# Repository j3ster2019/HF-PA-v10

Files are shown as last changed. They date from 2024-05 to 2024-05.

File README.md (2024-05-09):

Why?

We need a QRP PA which does NOT blow up (unlike those 3xBS170 and 4xBS170
designs). We believe that if the FETs blow up (despite best practices and
intentions but under less-than-ideal external conditions), then the design has
FAILED!

[Inspirational Video Link](https://www.youtube.com/watch?v=4r7wHMg5Yjg)

Important update (February-2024): LC match for IRF510 @ 28 MHz. 7 turns FT50-6
and 220pF capacitor. Corrected PAE figure is around 50%. 30v @ drain produces
roughly 10W of clean'ish looking RF output. 24v @ drain produces 6W @ 28 MHz.
17v @ drain produces 3.7W.

March-2024 update: LC match for IRF510 @ 50 MHz. T50-6 4 turns and 180pF
capacitor. 24v @ drain produces clean'ish 28.8 Vpp (~2W). PAE is around 25%.
Such is life...

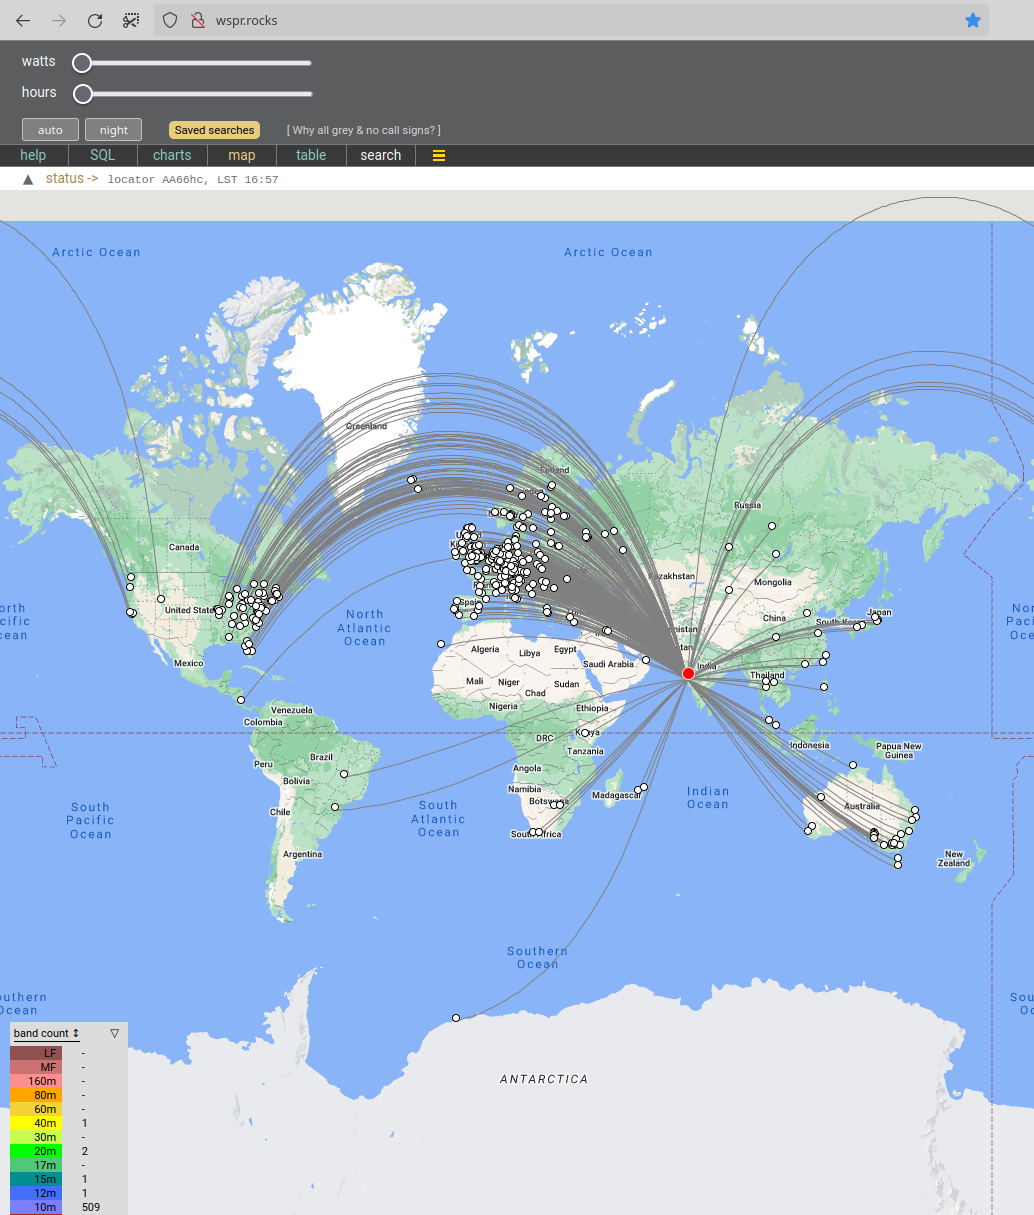
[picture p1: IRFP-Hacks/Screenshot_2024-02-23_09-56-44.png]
WSPR results


Update (29-September-2023): By removing the gate resistor, we firmly push the
amplifier into more Class-D operation. The MOSFET now remains as cool as a
cucumber!

Update (10-September-2023): The PCB was successfully validated!

Output is 7 to 8 W (before LPF) over a range of 160m to 10m as expected, with a
15V SMPS power supply. With a Pro-BPF attached, the power output is ~5W even at
28 MHz with IRF510! It even puts out 2W @ 50 MHz!

Amplifier characterization (@ 30.7 MHz for some reason, before LPF):

7 volts -> 2W

8 volts -> 3W

9 volts -> 3.5W

10 volts -> 4W

11 volts -> 5W

12 volts -> 6W

14 volts -> 8W

Efficiency is in the range of 45 to 50% which isn't bad ;)

Another result: 17 volts. 14 MHz. NKK LPF. 17.3W DC in. 57.6 clean Vpp on
scope. 8.3W clean RF output @ 48% efficiency!

BOM cost (minimal version): < 450 INR only - beat this! ;)

Note: HF-PA-v10 is also known as `CoolAMP (TM)`.

Build Notes:

- Use a 15V / 16v power supply.

- If you want to use a 13.8V power supply, then

  - Do NOT install the 78M12 regulator

  - Bridge the JP2 jumper

- Use adequate heatsinking. I use a 100x100x200 aluminium block with a 12v fan
  for doing WSPR activities. The MOSFET temperature stays under 45 degrees this
  way.

- PTT is active high - 3.3v is enough to trigger PTT.

- To skip the PTT sub-circuit, bridge the AOD407 MOSFET's source to drain.

- This amplifier can be directly driven by Si5351 (use 8mA drive setting)!

- IMPORTANT: For safety and RF output control, use a `10A DC-DC Step-down
  Adjustable Constant Voltage Module` or something similar.

  - https://robu.in/product/10a-dc-dc-step-down-adjustable-constant-voltage-module/

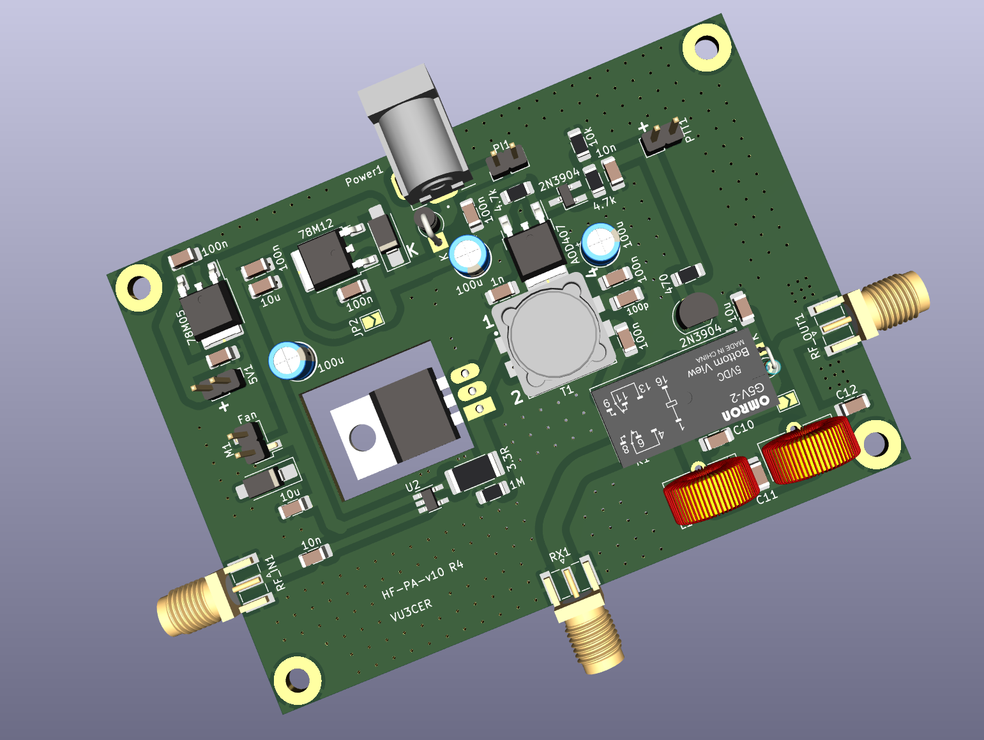
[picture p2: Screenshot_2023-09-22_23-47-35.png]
PA 1


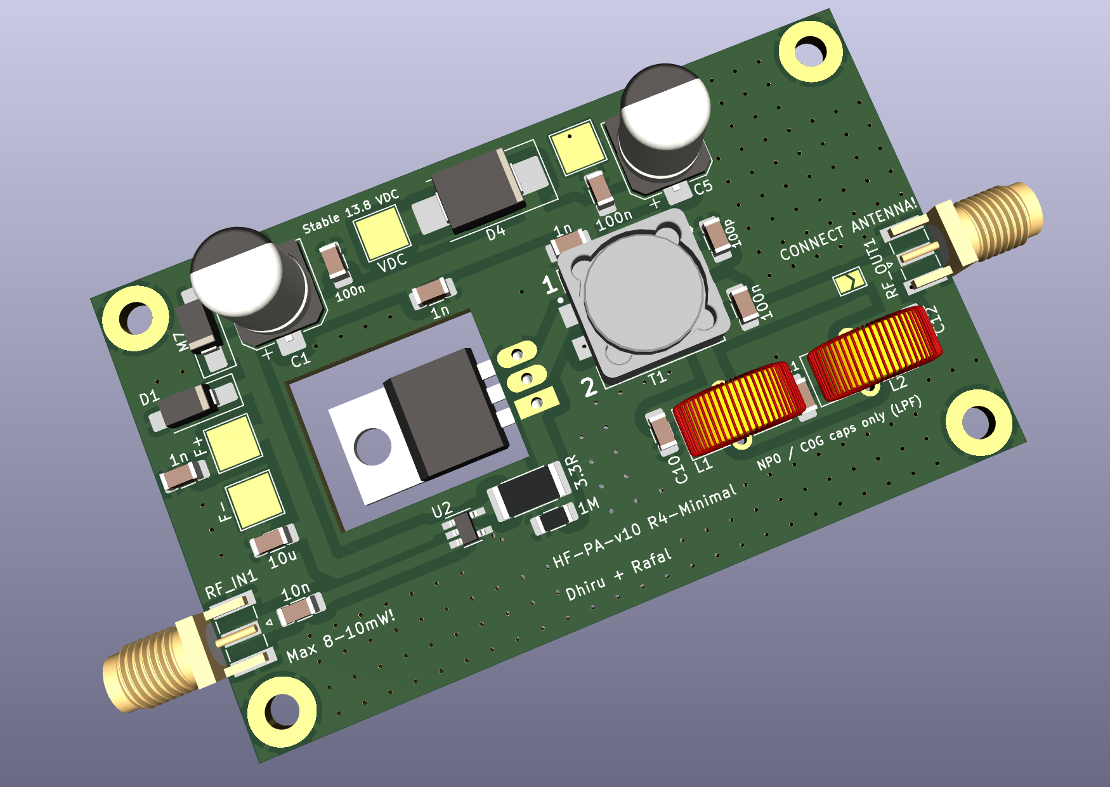
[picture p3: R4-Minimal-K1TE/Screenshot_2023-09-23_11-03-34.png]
PA Minimal


Results:

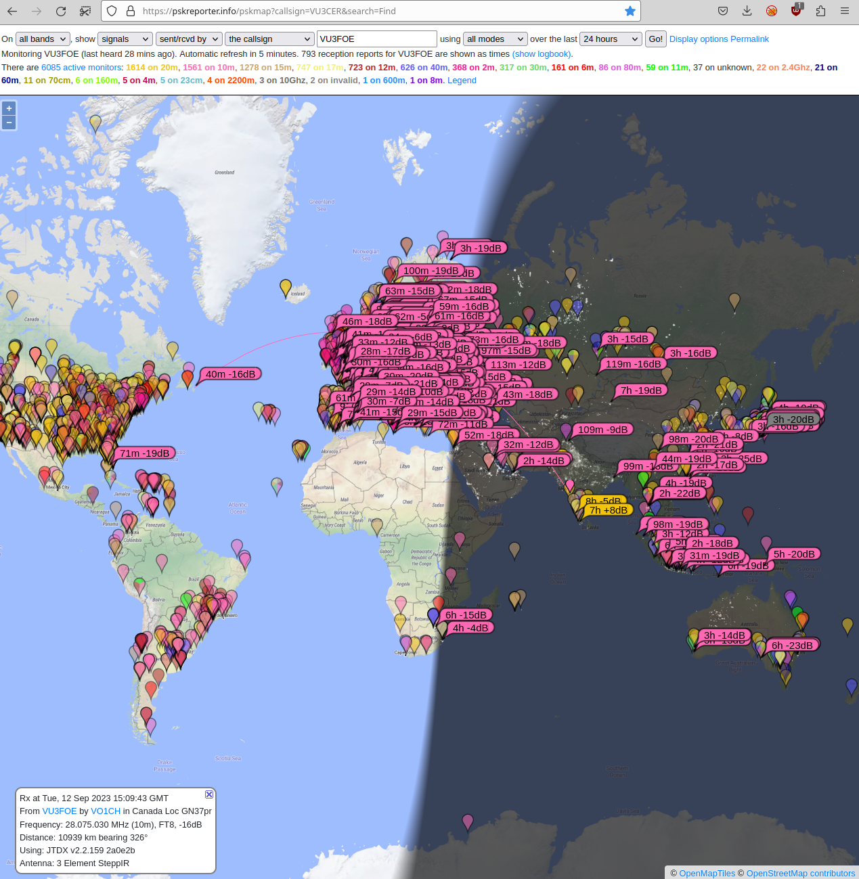
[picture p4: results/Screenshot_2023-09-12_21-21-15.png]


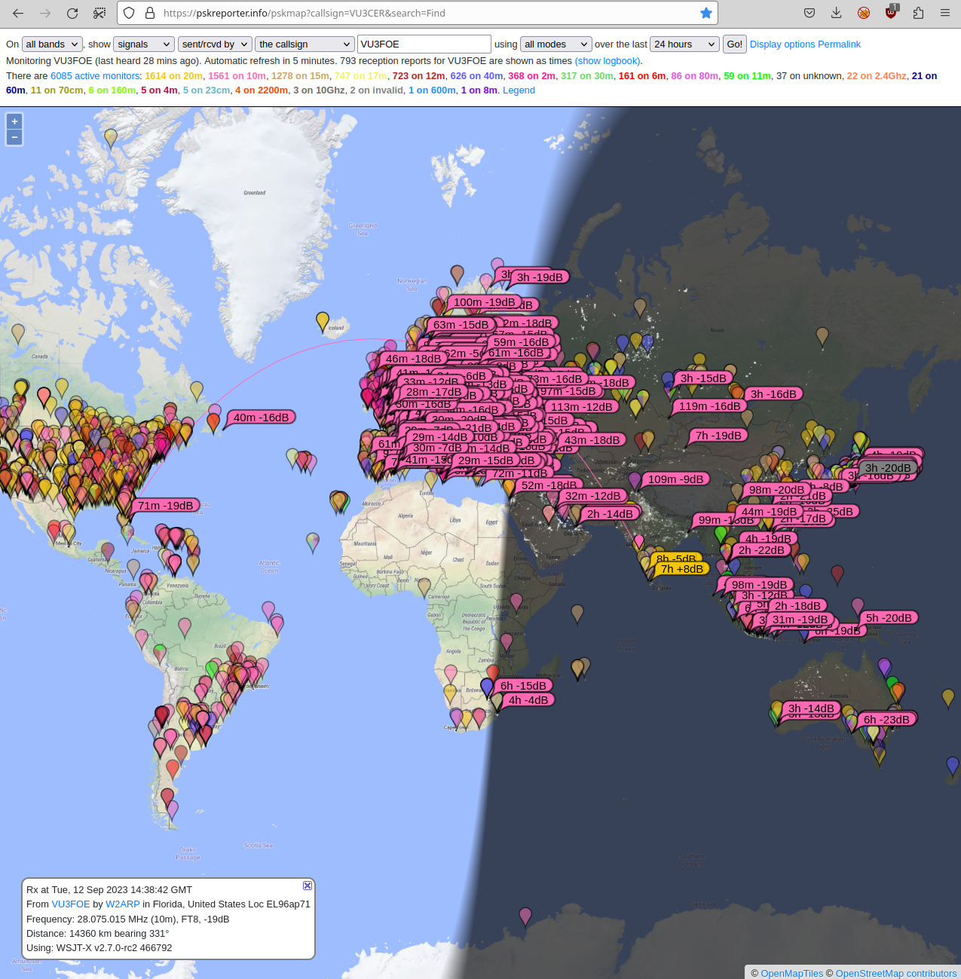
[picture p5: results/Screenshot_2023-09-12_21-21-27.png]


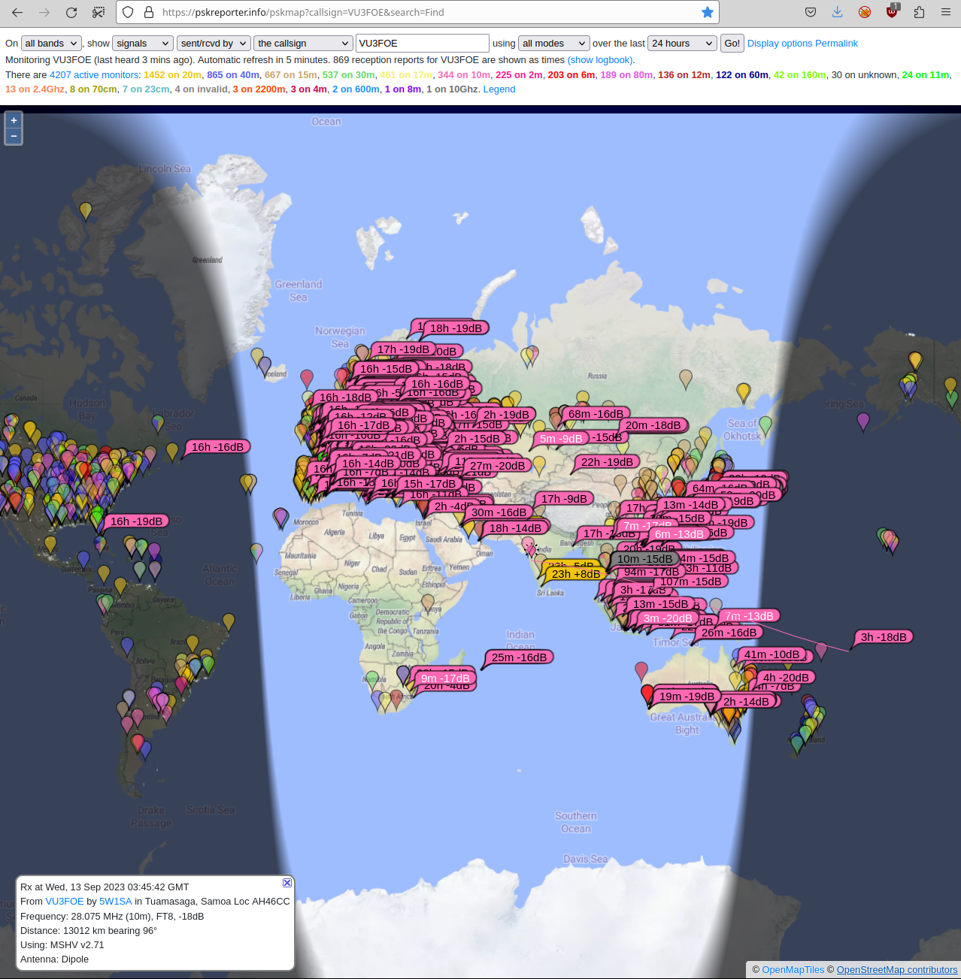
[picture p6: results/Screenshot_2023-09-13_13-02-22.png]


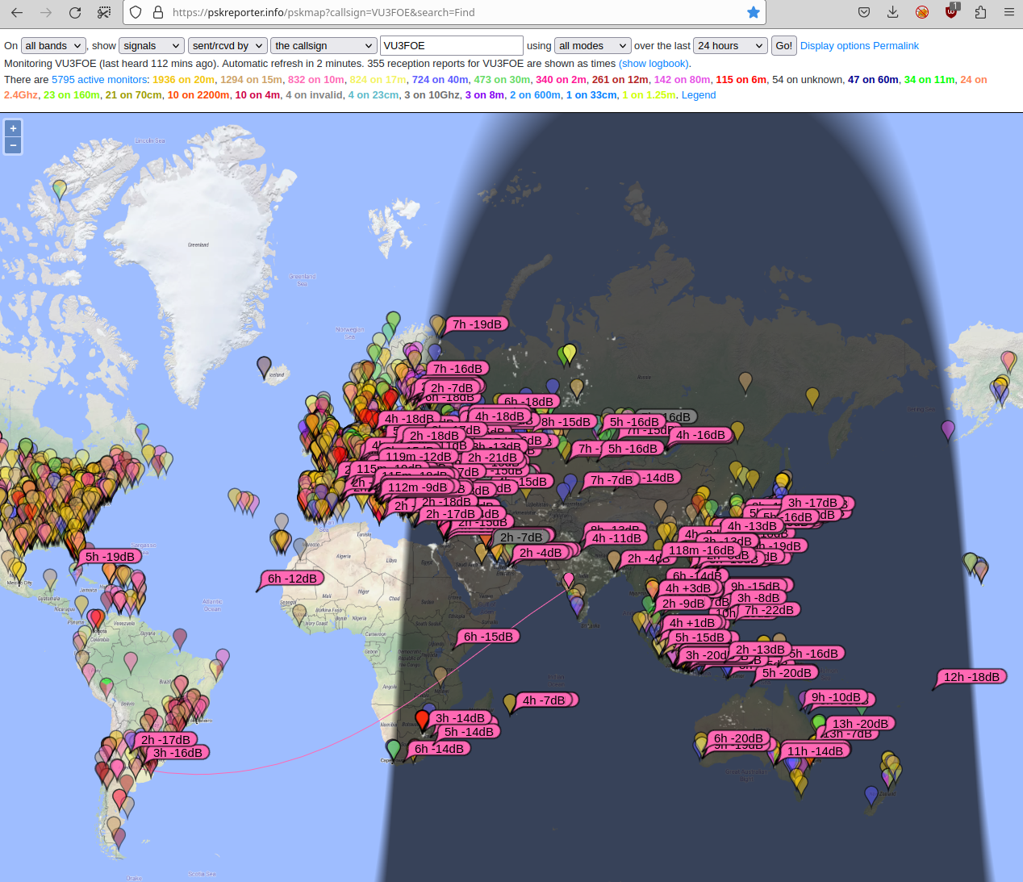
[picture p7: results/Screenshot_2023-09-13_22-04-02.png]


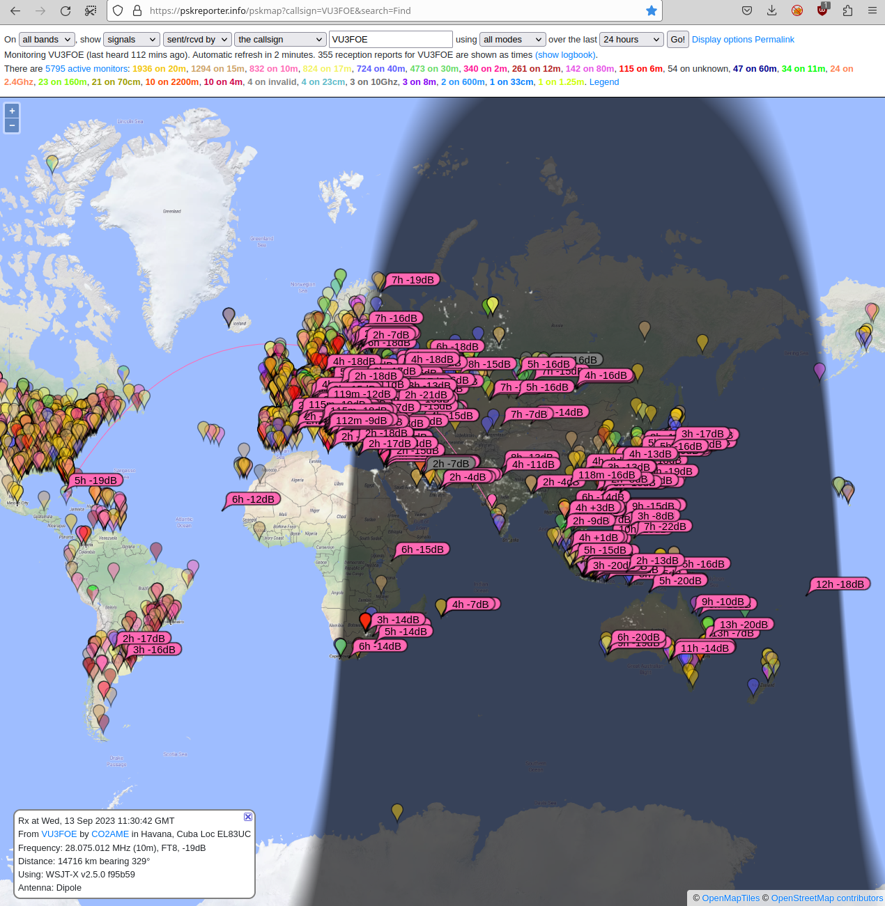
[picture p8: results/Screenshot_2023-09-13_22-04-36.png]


Fun on WSPR:

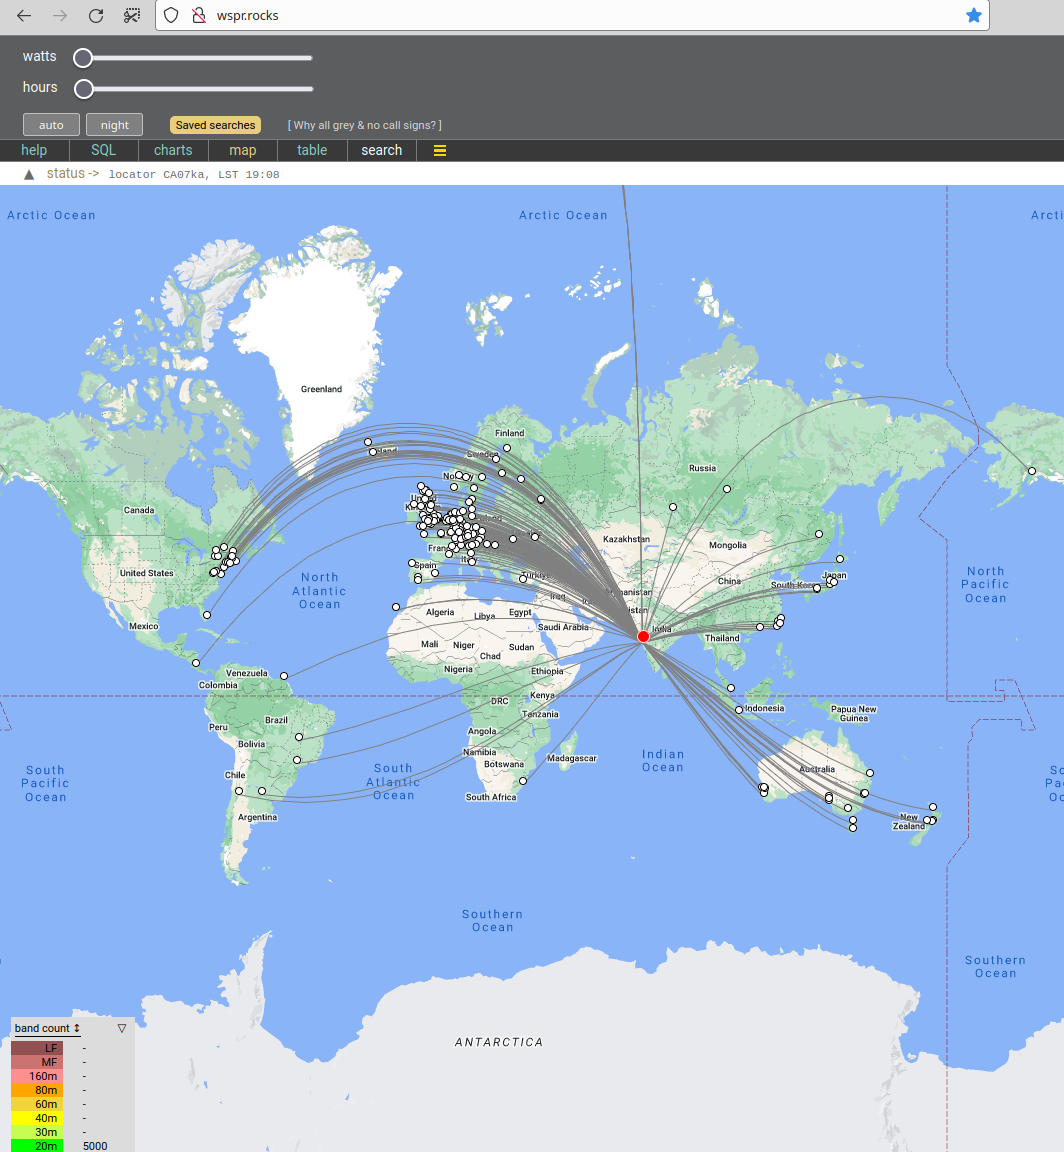
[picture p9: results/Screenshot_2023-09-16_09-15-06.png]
WSPR 1


Note: I am using a 5-meter long EFHW antenna tuned for the 10m band along with
~45 meters of HLF-240 coax. Your results should be better than mine ;)

Quick Hacks:

I am using one v10 board (on low power setting of ~1 to 2W) to drive the second
v10 board.

The second v10 board has IRF530 on it. It uses a simple 3R3 SMD drain choke,
240nH inductor (8 turns on T50-6) + 470 pF LC match for the 20m band at the
output side.

The power output is 20W+ with 30v at the IRF530 drain. While this is fine for
FT8, we decrease the output power to 9 to 12W for WSPR mode (considering
derating, heat dissipation, fear of "flash over")

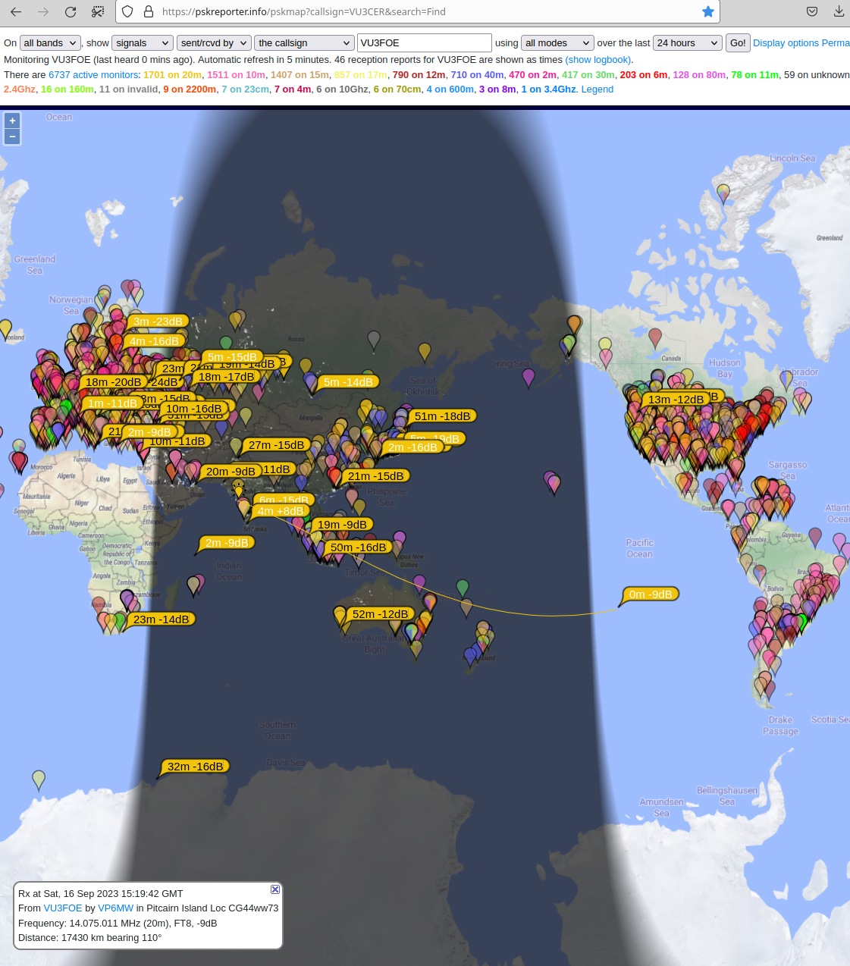
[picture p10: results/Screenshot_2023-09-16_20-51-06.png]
Results for IRF530 hack


December-2023 update: We can now use IRFP140N (with its massive TO-247 package)
to generate around "20W" safely for WSPR. We drive the IRFP140N MOSFET directly
with the UCC driver chip now.

Settings: UCC driver at roughly 12v. With LC match set for 20m band (NB!).

IRFP140N @ 28v drain @ 14 MHz -> 22W

IRFP140N @ 28v drain @ 3.5 MHz -> 20W (for Rafal)

IRFP140N @ 28v drain @ 7 MHz -> 20W

We believe we can push 25W easily by feeding 14v to 15v to the UCC driver chip.

The "final" IRFP140N MOSFET remains as cool as a cucumber, pretty boring -
right? Where have the "exciting" days of the MOSFETs blowing up in your face
gone? Just kidding!

NB: To overcome antenna losses (~2.0 SWR 20m dipole), lossy 50m meters of
HLF-200 coax, we need to generate around 15W+ on the amplifier side.

```
In [1]: 15W * 0.88 (SWR losses) * 0.40 (coax losses)
Out[1]: 5.28
```

PA protection:

- We plan to use INA219 to monitor current consumption, and to terminate TX if
  anomalies are detected.

- Use `thermocouple` attached to the MOSFET's body using thermoglue to monitor
  the temperature, and to terminate TX if anomalies are detected.

New discoveries (via https://github.com/rafal-rozestwinski):

- Power output is 1 to 1.5W on 50 MHz.

  We can probably get 2 to 3W with some more work here (push the amp into more
  Class-D).

- The PA survives open and short conditions but protections are recommended in
  any case.

  - INA219 based current monitoring

  - Thermocouple based temperature monitoring

- We do NOT recommend the old-skool SWR monitoring approach due to its
  complexity (for end-users).

Learnings:

- Keep the IRF510's gate voltage <=14 volts.

  If the IRF510's gate voltage is too high (i.e. when IRF510 is over-driven),
  it results in super wide-band distorted noisy signal on the output - you
  don't want that ;)

  If you want to feed high voltages to IRF's drain, then use a regulator (12v)
  for powering the UCC driver chip.

Joining In:

Are you interested in such projects, and spam-free technical discussions?

If yes, you might be interested in joining [the 'HAMBREWERS' Telegram group](https://t.me/+TwzGyKGe8_QI_B3y).

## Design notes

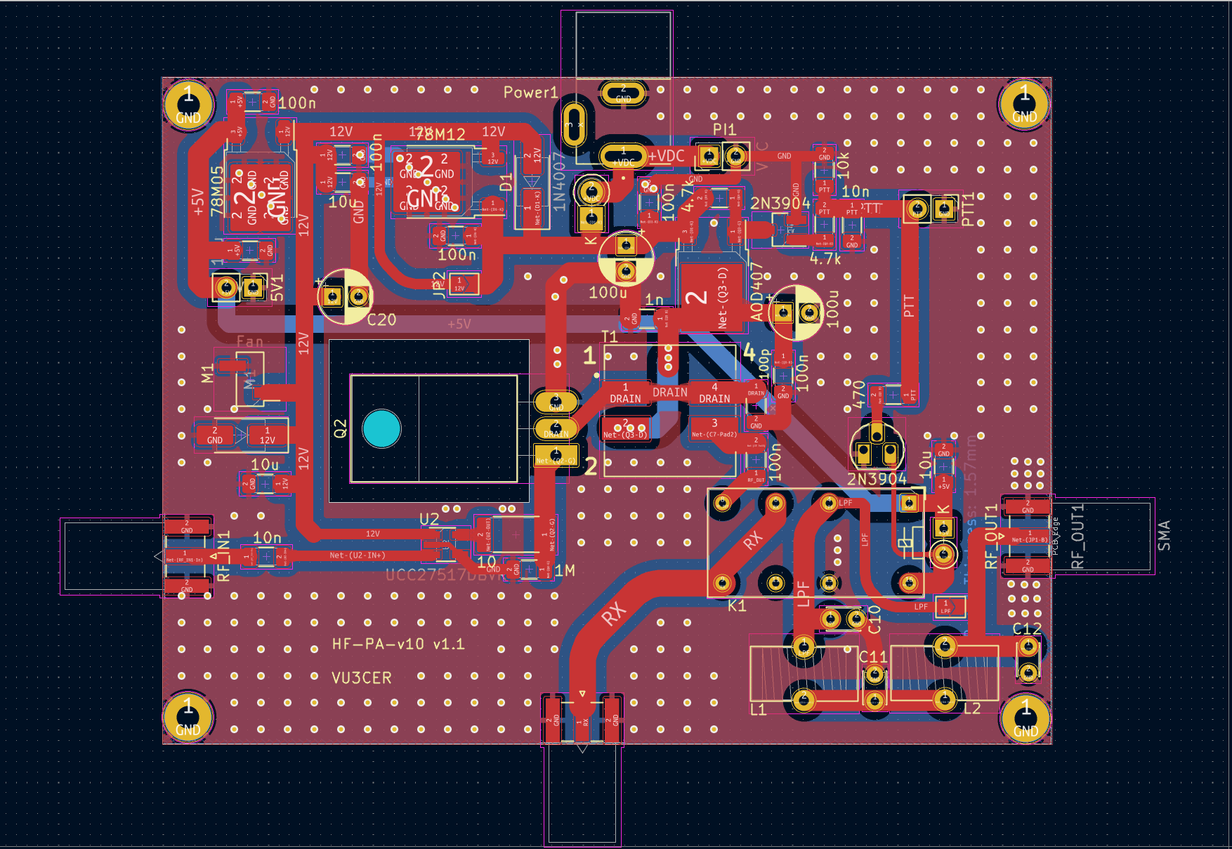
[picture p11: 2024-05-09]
Screenshot_2023-08-26_22-36-42.png

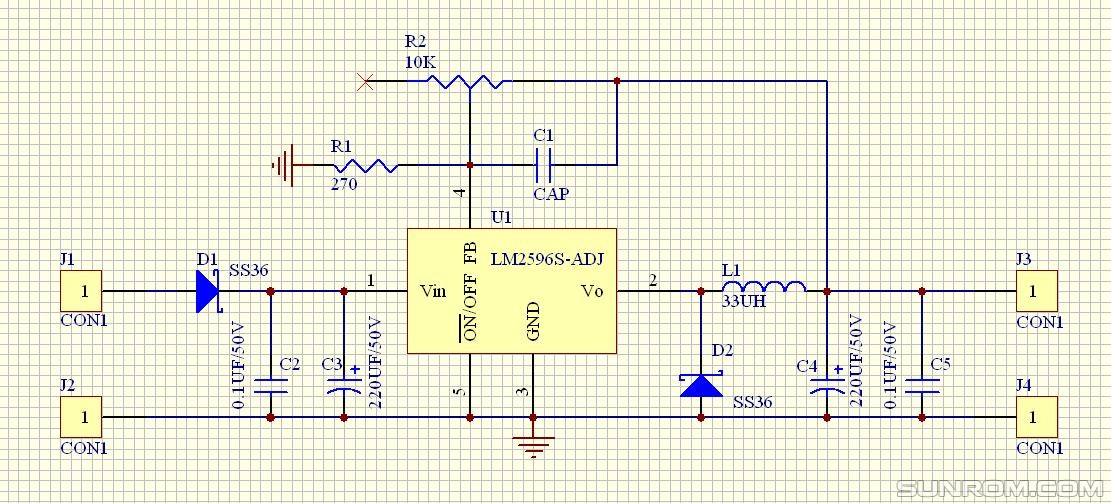
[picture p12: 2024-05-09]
FuturePowerControl/sch.jpg

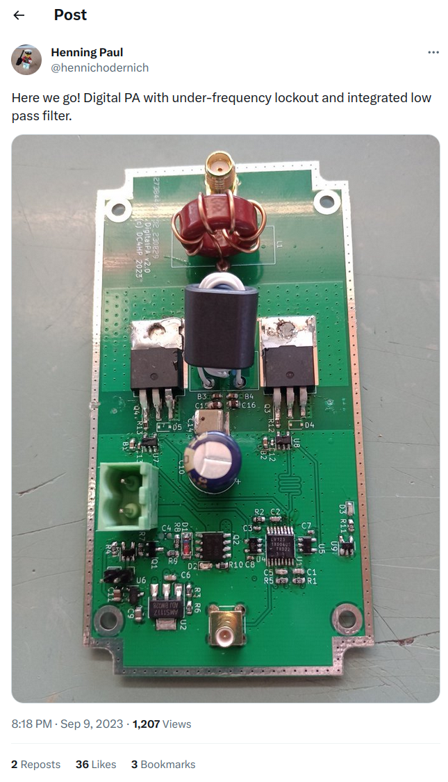
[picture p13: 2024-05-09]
info/Screenshot_2023-09-10_00-21-56.png

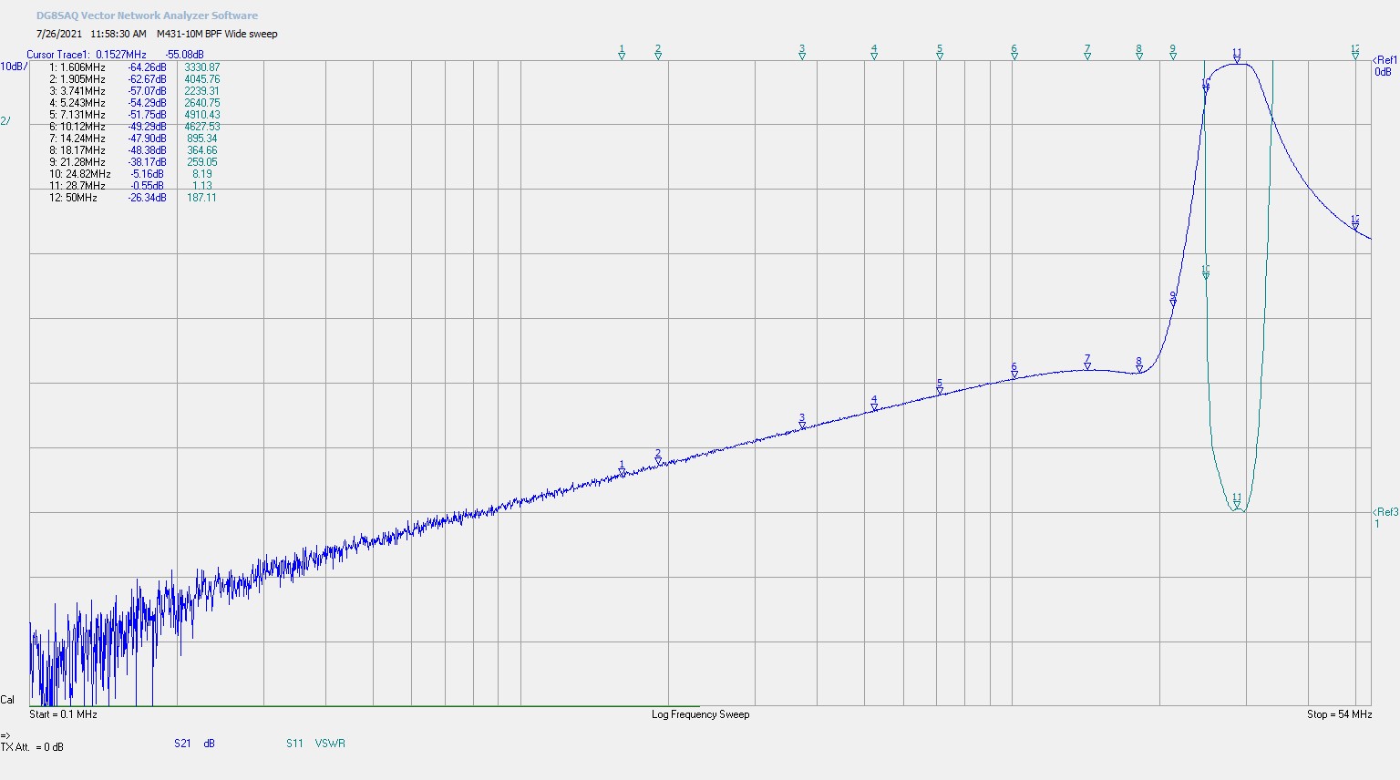
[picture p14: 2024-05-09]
info/M431_10M_Wide.jpg

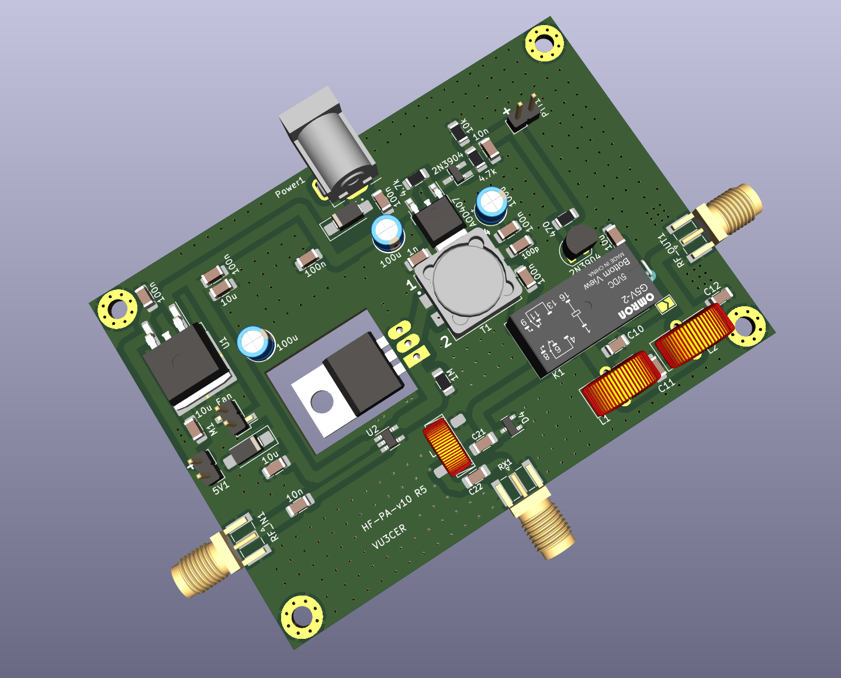
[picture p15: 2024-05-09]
R5/Screenshot_2023-10-03_14-03-06.png

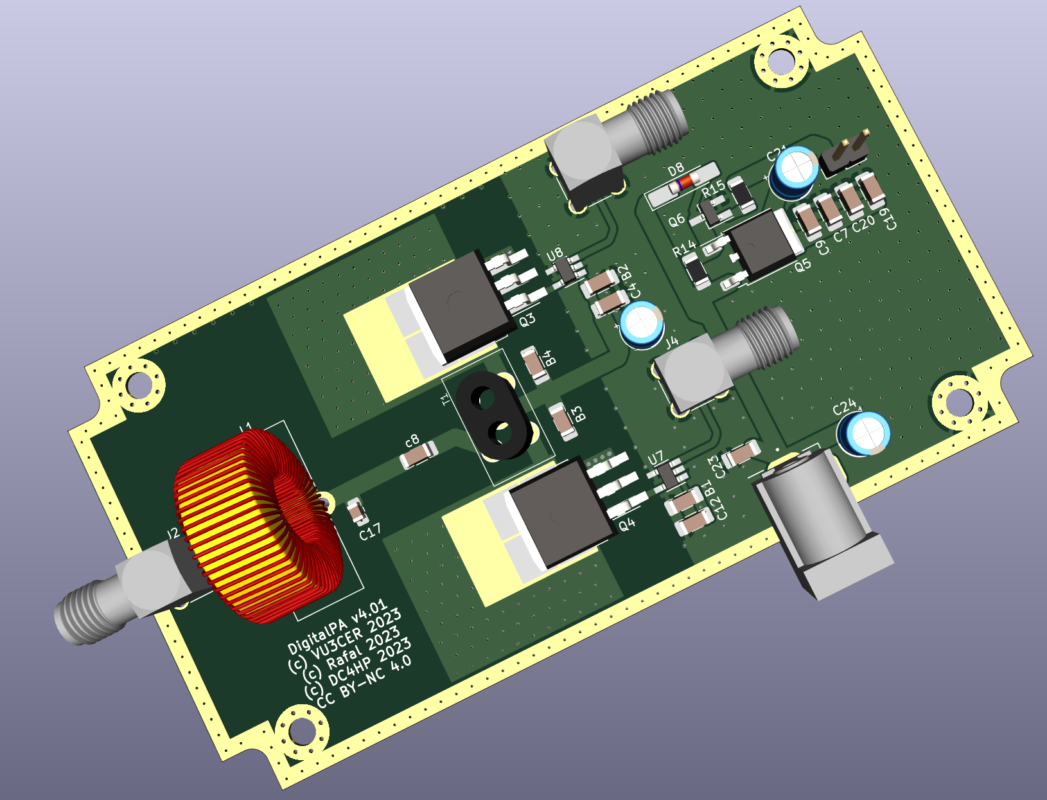
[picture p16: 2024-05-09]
Digital-PA-v3/Screenshot_2023-10-04_21-27-38.png

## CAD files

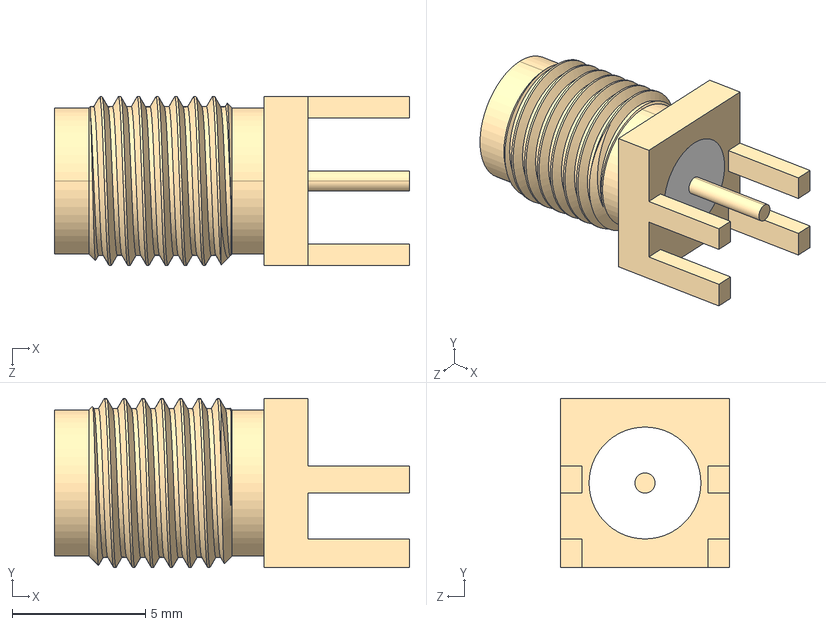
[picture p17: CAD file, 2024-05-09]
Digital-PA-v3/models/CON-SMA-EDGE-S--3DModel-STEP-56544.STEP
13.3 x 6.35 x 6.35 mm

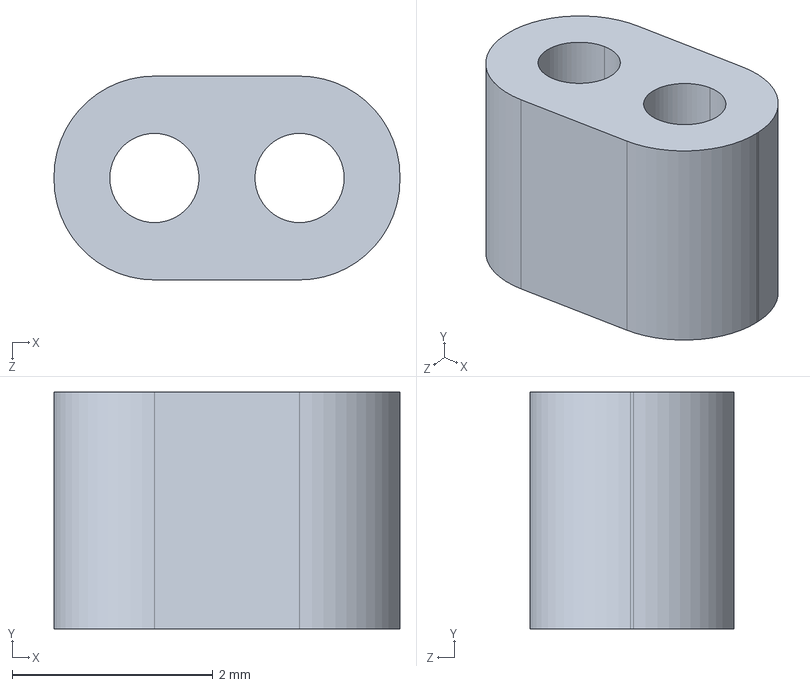
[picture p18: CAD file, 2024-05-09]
Digital-PA-v5-Prod/models/User Library-BN43-2302.STEP
3.45 x 2.36 x 2.03 mm

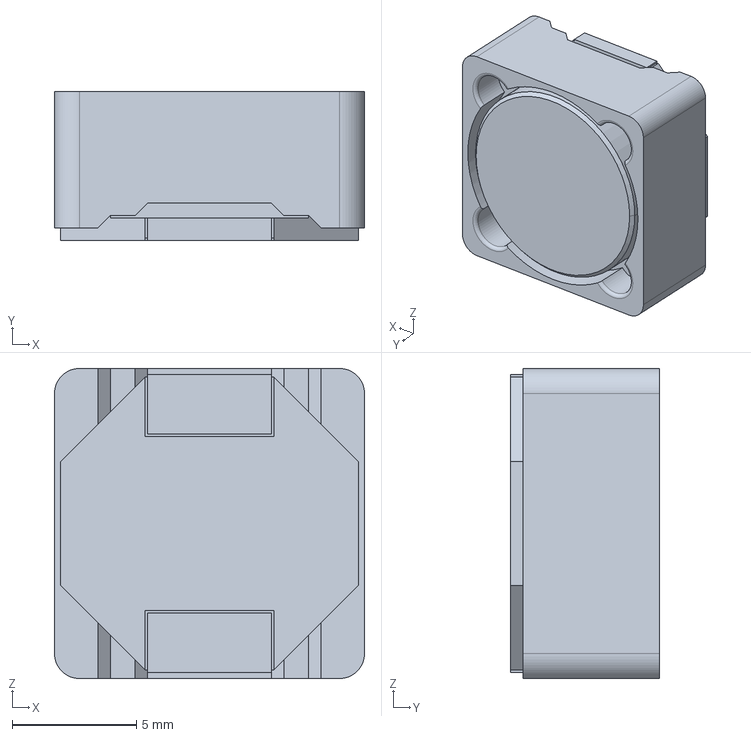
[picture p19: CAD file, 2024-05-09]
FuturePowerControl/models/SRR1260-4R7Y.stp
12.5 x 6.00 x 12.5 mm

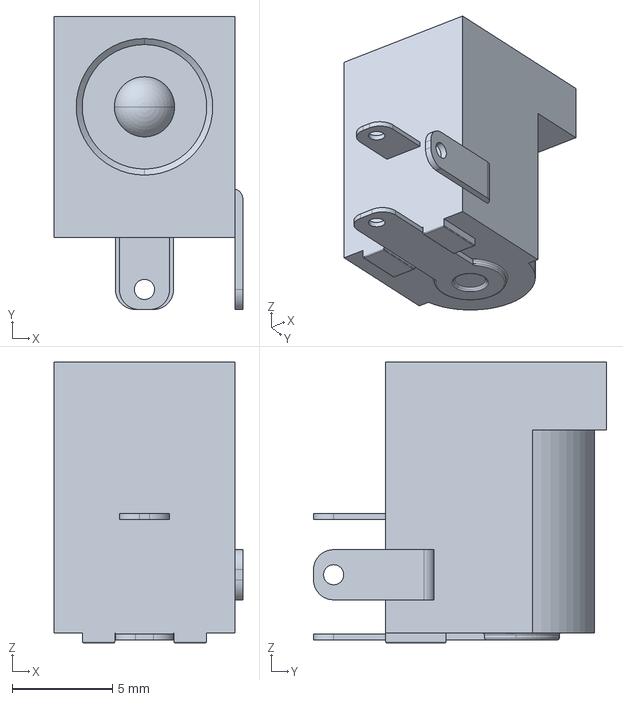
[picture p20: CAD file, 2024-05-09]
IRFP-Hacks-v4/models/DC-005-5A-2.0.step
9.40 x 14.6 x 14.0 mm

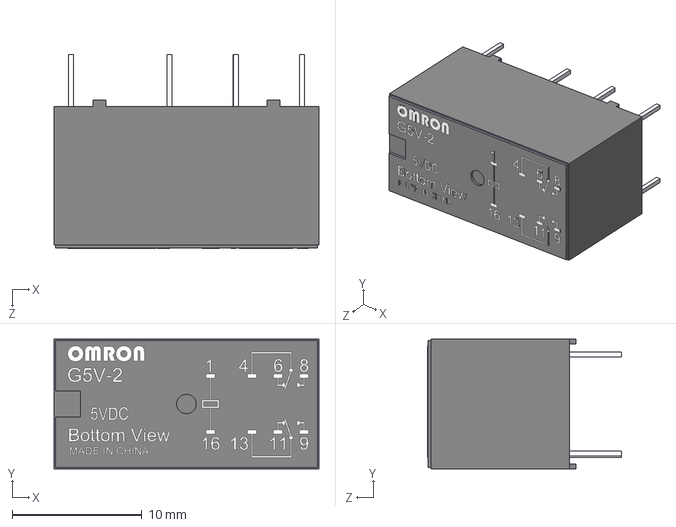
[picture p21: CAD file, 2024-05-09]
R4-Minimal-K1TE/models/User Library-OMRON G5V-2.STEP
20.4 x 10.0 x 14.9 mm

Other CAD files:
Digital-PA-v3/models/144743.stp
Digital-PA-v3/models/UCC27517DBVR.step
Digital-PA-v5-Prod/models/144743.stp
Digital-PA-v5-Prod/models/UCC27517DBVR.step
FuturePowerControl/models/UCC27517DBVR.step
IRF530-Hack/models/Inductor_7x7x2.5.STEP
IRF530-Hack/models/UCC27517DBVR.step
IRFP-Hacks-v2/models/Inductor_7x7x2.5.STEP
IRFP-Hacks-v2/models/UCC27517DBVR.step
IRFP-Hacks-v3/models/Inductor_7x7x2.5.STEP
IRFP-Hacks-v3/models/UCC27517DBVR.step
IRFP-Hacks-v4/models/Inductor_7x7x2.5.STEP
IRFP-Hacks-v4/models/TO-220-3 Bend Mirror.stp
IRFP-Hacks-v4/models/UCC27517DBVR.step
IRFP-Hacks/models/Inductor_7x7x2.5.STEP
IRFP-Hacks/models/UCC27517DBVR.step
MRF101-Hack/models/DG340-3.81-02P-12-00AH.STEP
MRF101-Hack/models/Inductor_7x7x2.5.STEP
MRF101-Hack/models/Screw-Terminal-P5.08.step
MRF101-Hack/models/UCC27517DBVR.step
MRF101-Hack/models/User Library-3386P.STEP
MRF101-Hack/models/WE-CAIR_4248 (rev1).stp
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

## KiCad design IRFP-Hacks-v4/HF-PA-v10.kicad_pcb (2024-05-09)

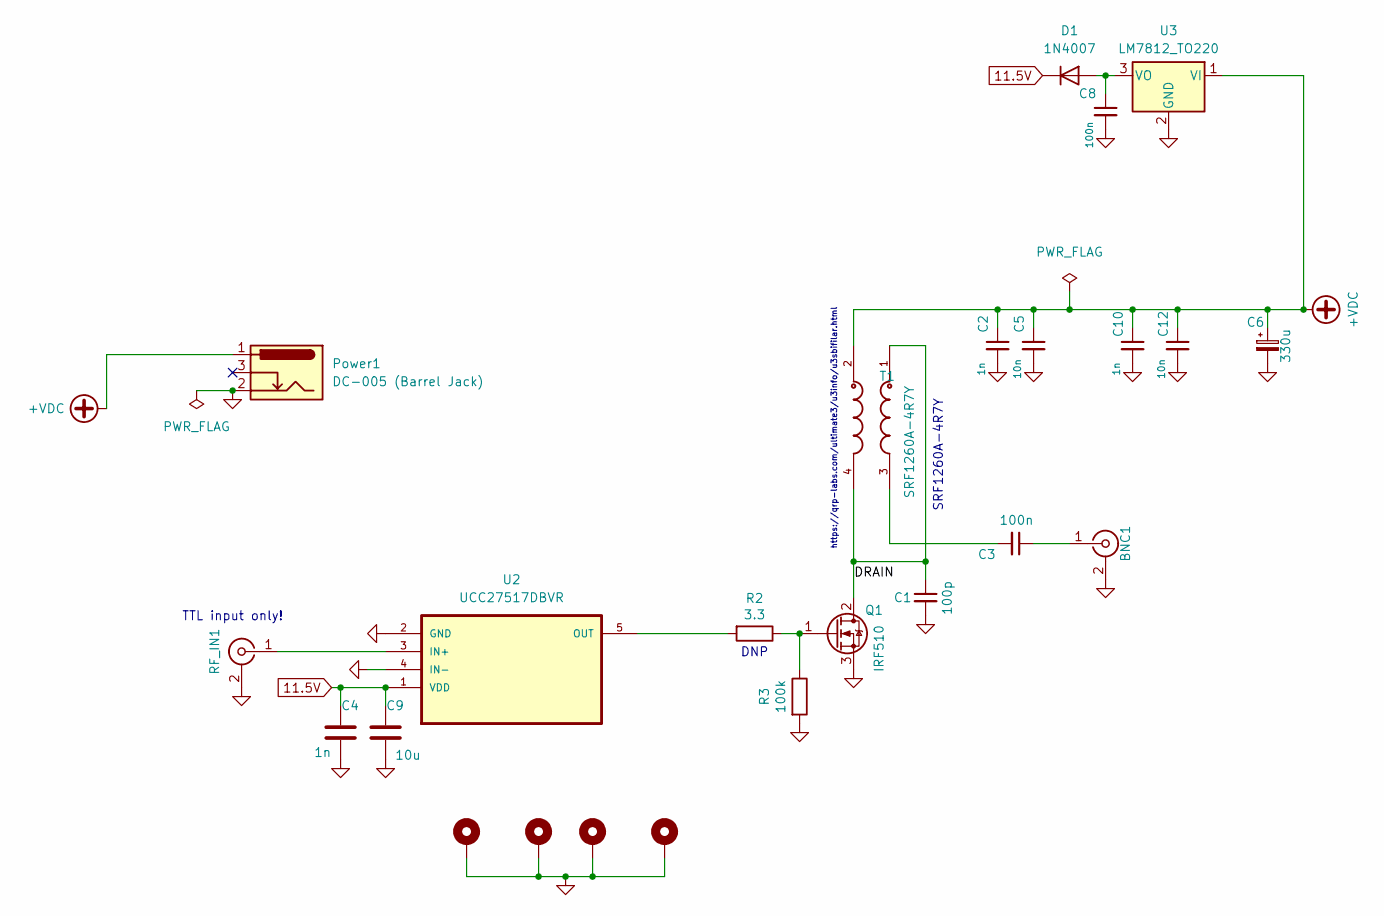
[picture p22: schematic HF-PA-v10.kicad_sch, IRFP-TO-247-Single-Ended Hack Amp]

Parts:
BNC1: SMA; SMA_Samtec_SMA-J-P-X-ST-EM1_EdgeMount
C1: 100p; C_1206_3216Metric_Pad1.33x1.80mm_HandSolder
C2, C4, C10: 1n; C_1206_3216Metric_Pad1.33x1.80mm_HandSolder
C3, C8: 100n; C_1206_3216Metric_Pad1.33x1.80mm_HandSolder
C5, C12: 10n; C_1206_3216Metric_Pad1.33x1.80mm_HandSolder
C6: 330u; CP_Radial_D8.0mm_P5.00mm
C9: 10u; C_1206_3216Metric_Pad1.33x1.80mm_HandSolder
D1: 1N4007; D_DO-41_SOD81_P2.54mm_Vertical_KathodeUp
H1, H2, H3, H4: MountingHole_Pad; MountingHole_3.2mm_M3_Pad_Via
Power1: DC-005 (Barrel Jack); XKB_DC-005-5A-2.0_Modded
Q1: IRF510; TO-247-3_Horizontal_TabDown_Modded
R2: 3.3; R_1206_3216Metric_Pad1.30x1.75mm_HandSolder
R3: 100k; R_1206_3216Metric_Pad1.30x1.75mm_HandSolder
RF_IN1: SMA; SMA_Samtec_SMA-J-P-X-ST-EM1_EdgeMount
T1: SRF1260A-4R7Y; IND_SRF1260A-4R7Y-Longer-Pads
U2: UCC27517DBVR; TSOT-23-5_HandSoldering
U3: LM7812_TO220; TO-220-3_Horizontal_TabDown

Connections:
11.5V: C4.1, C9.1, D1.1 (K), U2.1 (VDD)
+VDC: C2.1, C5.1, C6.1, C10.1, C12.1, Power1.1, T1.2, U3.1 (VI)
/DRAIN: C1.1, Q1.2 (D), T1.1, T1.4
GND: C1.2, C2.2, C4.2, C5.2, C6.2, C8.2, C9.2, C10.2, C12.2, H1.1, H2.1, H3.1, H4.1, Power1.2, Q1.3 (S), R3.2, RF_IN1.2 (Ext), U2.2 (GND), U2.4 (IN-), U3.2 (GND); also elsewhere on the board
unnamed: C3.2, T1.3
unnamed: C8.1, D1.2 (A), U3.3 (VO)
unnamed: Q1.1 (G), R2.1, R3.1
unnamed: RF_IN1.1 (In), U2.3 (IN+)
unnamed 8: C3.1; also elsewhere on the board
unnamed: R2.2, U2.5 (OUT)

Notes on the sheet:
DNP
https://qrp-labs.com/ultimate3/u3info/u3sbifilar.html
SRF1260A-4R7Y
TTL input only!

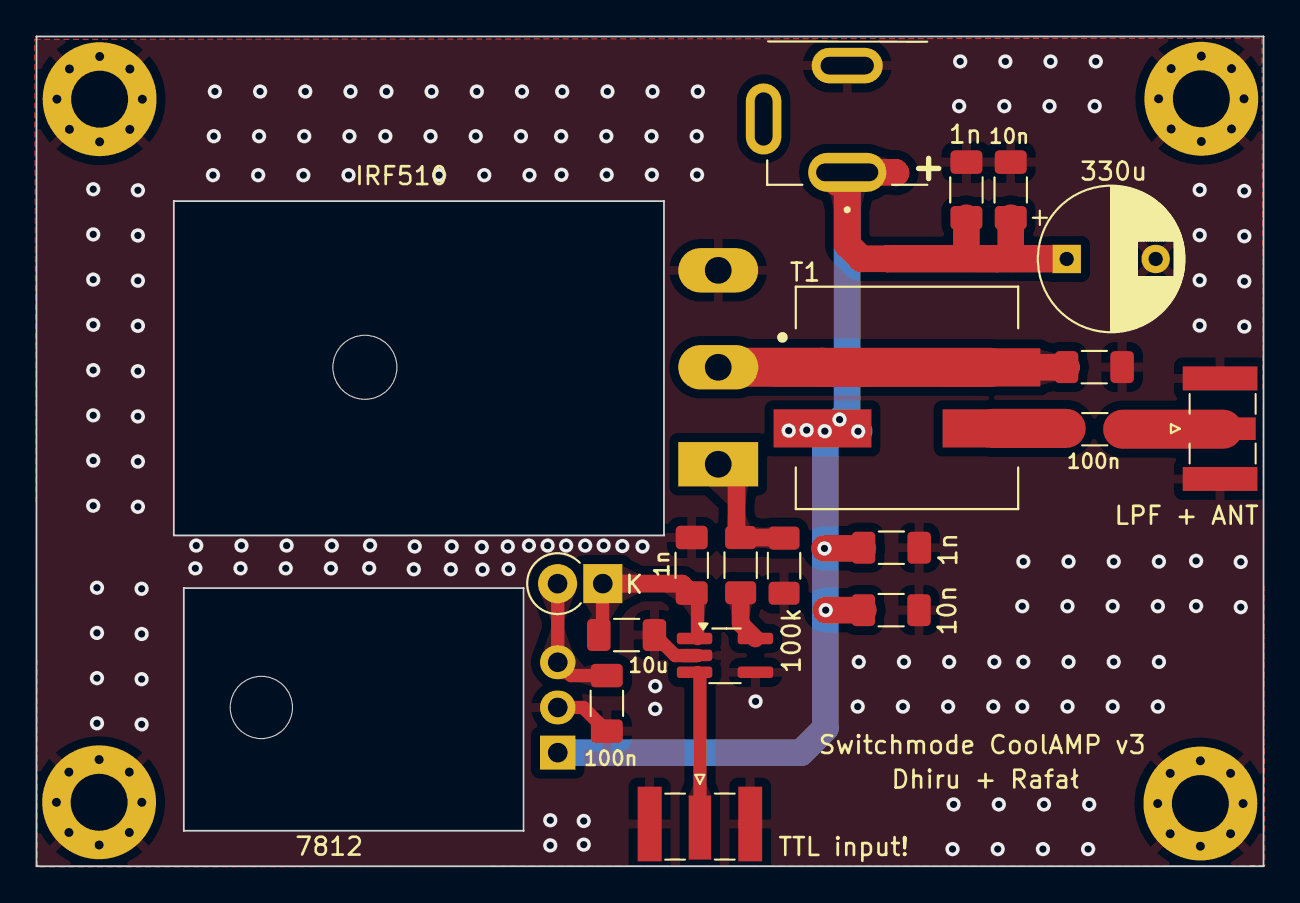
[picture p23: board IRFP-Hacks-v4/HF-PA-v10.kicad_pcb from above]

Board: 2 copper layers, 69.0 x 46.6 mm, 24 parts (0 on the bottom side), 10 nets.

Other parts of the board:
RF_OUT1: SMA; SMA_Samtec_SMA-J-P-X-ST-EM1_EdgeMount

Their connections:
GND: RF_OUT1.2 (Ext); also elsewhere on the board
unnamed 8: RF_OUT1.1 (In); also elsewhere on the board

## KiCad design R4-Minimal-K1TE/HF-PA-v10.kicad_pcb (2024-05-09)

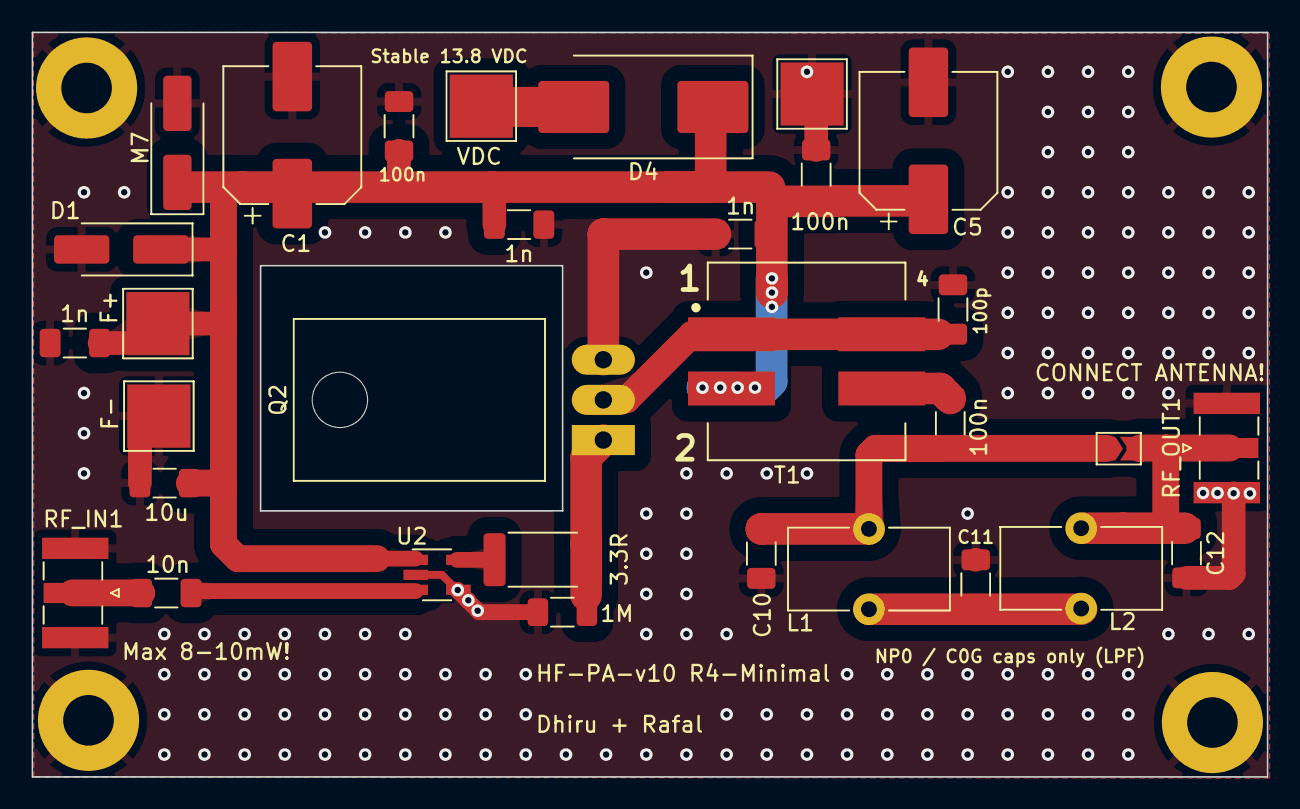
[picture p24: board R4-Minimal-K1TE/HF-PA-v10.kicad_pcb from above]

Board: 2 copper layers, 78.1 x 47.1 mm, 35 parts (0 on the bottom side), 12 nets.

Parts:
C1, C5: 220u; CP_Elec_8x10.5
C2, C4, C17: 1n; C_1206_3216Metric_Pad1.33x1.80mm_HandSolder
C3: 100p; C_1206_3216Metric_Pad1.33x1.80mm_HandSolder
C6, C7, C14: 100n; C_1206_3216Metric_Pad1.33x1.80mm_HandSolder
C10, C12: 120p; C_1206_3216Metric_Pad1.33x1.80mm_HandSolder
C11: 200p; C_1206_3216Metric_Pad1.33x1.80mm_HandSolder
C16: 10u; C_1206_3216Metric_Pad1.33x1.80mm_HandSolder
C19: 10n; C_1206_3216Metric_Pad1.33x1.80mm_HandSolder
D1: 18v; D_SMA_Handsoldering
D2: M7; D_SMA_Handsoldering
D4: 2A+ Schottky (SS34 or similar); D_SMC_Handsoldering
Fan+1: F+; TestPoint_Pad_4.0x4.0mm
Fan-1: F-; TestPoint_Pad_4.0x4.0mm
H1, H2, H3, H4: MountingHole_Pad; MountingHole_3.2mm_M3_Pad
JP1: Jumper_2_Open; SolderJumper-2_P1.3mm_Open_TrianglePad1.0x1.5mm
L1, L2: 360n; L_Toroid_Vertical_L10.0mm_W5.0mm_P5.08mm
PI1: VDC; TestPoint_Pad_4.0x4.0mm
PI2: GND; TestPoint_Pad_4.0x4.0mm
Q2: IRF510; TO-220-3_Horizontal_TabDown
R1: 1M; R_1206_3216Metric_Pad1.30x1.75mm_HandSolder
R3: 3.3R; R_2512_6332Metric_Pad1.40x3.35mm_HandSolder
RF_IN1: SMA; SMA_Samtec_SMA-J-P-X-ST-EM1_EdgeMount
RF_OUT1: SMA; SMA_Samtec_SMA-J-P-X-ST-EM1_EdgeMount
T1: Bifilar XFMR; IND_SRF1260A-4R7Y-Longer-Pads
U2: UCC27517DBVR; SOT-23-5_HandSoldering

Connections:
12V: C1.1, C2.1, C4.1, C5.1, C6.1, C14.1, C16.1, C17.1, D1.1 (K), D2.1 (K), D4.1 (K), Fan+1.1, T1.2, U2.1 (VDD)
+VDC: D4.2 (A), PI1.1
/DRAIN: C3.1, Q2.2 (D), T1.1, T1.4
GND: C1.2, C2.2, C3.2, C4.2, C5.2, C6.2, C10.2, C11.2, C12.2, C14.2, C16.2, C17.2, D1.2 (A), D2.2 (A), Fan-1.1, H1.1, H2.1, H3.1, H4.1, PI2.1, Q2.3 (S), R1.2, RF_IN1.2 (Ext), RF_OUT1.2 (Ext), U2.2 (GND), U2.4 (IN-)
unnamed: C7.2, T1.3
unnamed: C11.1, L1.2, L2.1
unnamed: C7.1, C10.1, JP1.1 (A), L1.1
unnamed: C12.1, JP1.2 (B), L2.2, RF_OUT1.1 (In)
unnamed: Q2.1 (G), R1.1, R3.1
unnamed: C19.1, RF_IN1.1 (In)
unnamed: C19.2, U2.3 (IN+)
unnamed: R3.2, U2.5 (OUT)

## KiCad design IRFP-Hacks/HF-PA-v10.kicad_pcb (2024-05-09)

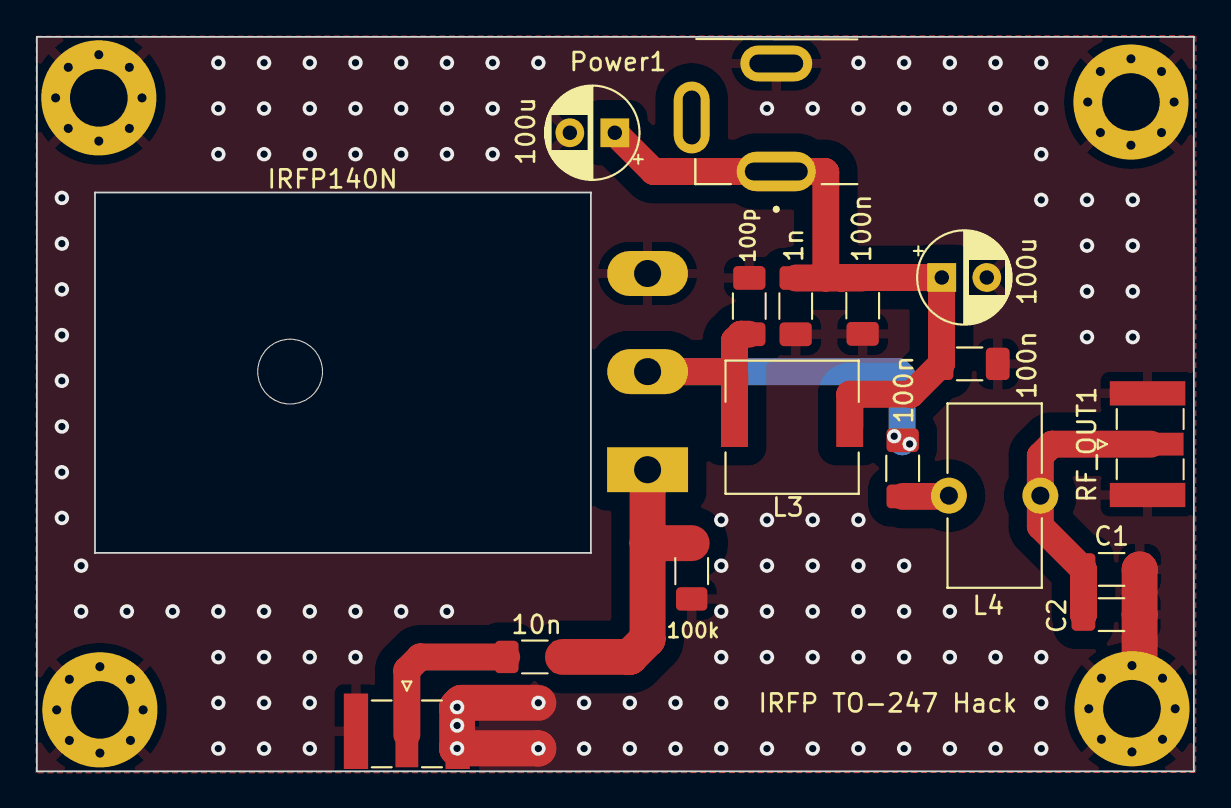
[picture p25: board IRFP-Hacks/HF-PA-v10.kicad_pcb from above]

Board: 2 copper layers, 64.3 x 40.8 mm, 21 parts (0 on the bottom side), 7 nets.

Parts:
C1: 470p; C_1206_3216Metric_Pad1.33x1.80mm_HandSolder
C2: Trim; C_1206_3216Metric_Pad1.33x1.80mm_HandSolder
C3: 100p; C_1206_3216Metric_Pad1.33x1.80mm_HandSolder
C5, C15: 100u; CP_Radial_D5.0mm_P2.50mm
C6, C7, C14: 100n; C_1206_3216Metric_Pad1.33x1.80mm_HandSolder
C17: 1n; C_1206_3216Metric_Pad1.33x1.80mm_HandSolder
C19: 10n; C_1206_3216Metric_Pad1.33x1.80mm_HandSolder
H1, H2, H3, H4: MountingHole_Pad; MountingHole_3.2mm_M3_Pad_Via
L3: 3.3uH / 4.7uH; L_7.3x7.3_H3.5
L4: 240n; L_Toroid_Vertical_L10.0mm_W5.0mm_P5.08mm
Power1: DC-005 (Barrel Jack); XKB_DC-005-5A-2.0_Modded
Q1: IRFP140N; TO-247-3_Horizontal_TabDown_Modded
R1: 100k; R_1206_3216Metric_Pad1.30x1.75mm_HandSolder
RF_IN1: SMA; SMA_Samtec_SMA-J-P-X-ST-EM1_EdgeMount
RF_OUT1: SMA; SMA_Samtec_SMA-J-P-X-ST-EM1_EdgeMount

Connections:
+VDC: C5.1, C6.1, C14.1, C15.1, C17.1, L3.1, Power1.1
/DRAIN: C3.1, C7.2, L3.2, Q1.2 (D)
GND: C1.2, C2.2, C3.2, C5.2, C6.2, C14.2, C15.2, C17.2, H1.1, H2.1, H3.1, H4.1, Power1.2, Q1.3 (S), R1.2, RF_IN1.2 (Ext), RF_OUT1.2 (Ext)
unnamed: C7.1, L4.1
unnamed: C19.2, Q1.1 (G), R1.1
unnamed: C19.1, RF_IN1.1 (In)
unnamed: C1.1, C2.1, L4.2, RF_OUT1.1 (In)

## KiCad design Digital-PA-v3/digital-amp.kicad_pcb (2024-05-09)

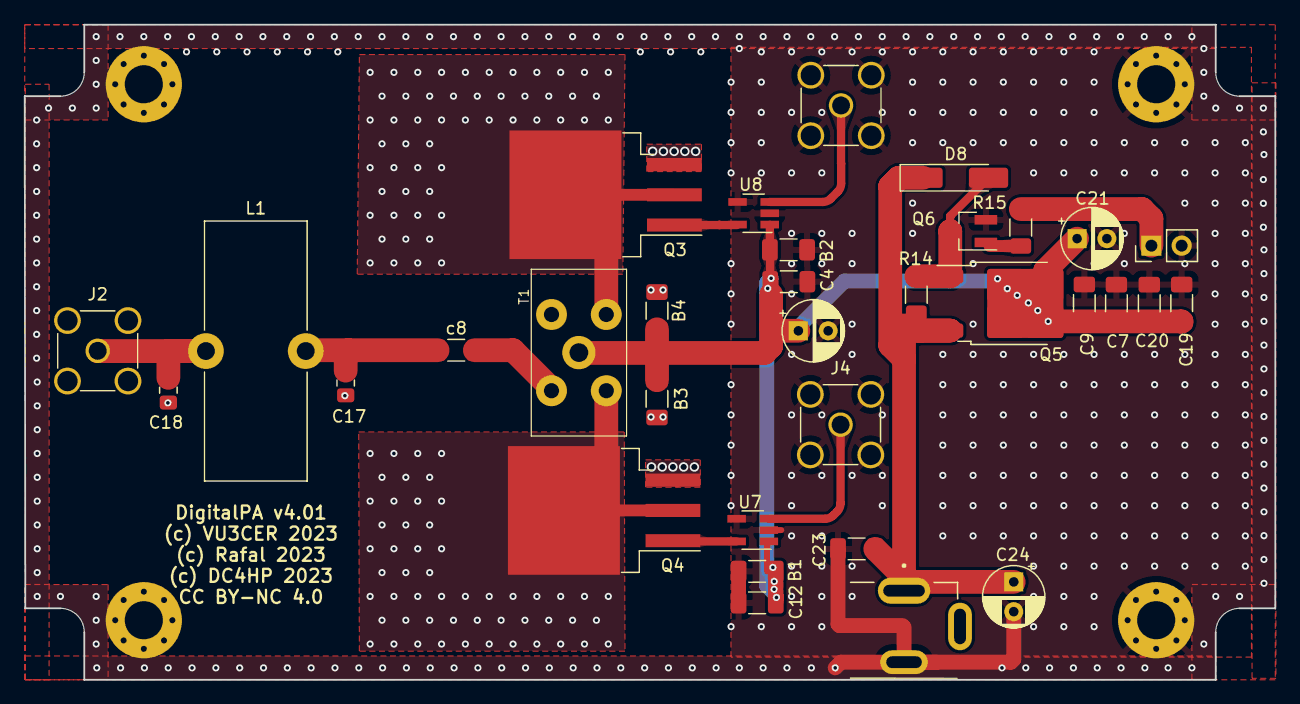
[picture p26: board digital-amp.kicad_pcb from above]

Board: 2 copper layers, 105.0 x 55.0 mm, 37 parts (0 on the bottom side), 15 nets.

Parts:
B1, B2, B3, B4: 0.1uF; C_1206_3216Metric_Pad1.33x1.80mm_HandSolder
C4, C7, C12, C19: 1n; C_1206_3216Metric_Pad1.33x1.80mm_HandSolder
C9, C20, C23: 100n; C_1206_3216Metric_Pad1.33x1.80mm_HandSolder
C10, C21, C24: 100u; CP_Radial_D5.0mm_P2.50mm
C17, C18: 100p; C_0805_2012Metric_Pad1.18x1.45mm_HandSolder
D8: 5.1V; D_MiniMELF_Handsoldering
H1, H2, H3, H4: MountingHole_Pad; MountingHole_3.2mm_M3_Pad_Via
J1, J2, J4: Conn_Coaxial; SMA_Amphenol_901-144_Vertical
J3: Conn_01x02_Male; PinHeader_1x02_P2.54mm_Vertical
L1: 318.5nH; L_Toroid_Vertical_L21.6mm_W8.4mm_P8.38mm_Pulse_G
Power1: DC-005 (Barrel Jack); XKB_DC-005-5A-2.0_Modded
Q3, Q4: IRF510; TO-263-3_TabPin2
Q5: AOD407; TO-252-2
Q6: 2N3904; SOT-23_Handsoldering
R14: 100k; R_1206_3216Metric_Pad1.30x1.75mm_HandSolder
R15: 4.7k; R_1206_3216Metric_Pad1.30x1.75mm_HandSolder
T1: BN-61-202, 2+2T:6T; BN202V
U7, U8: UCC27517DBVR; SOT-23-5_HandSoldering
c8: 0.1uF; C_1206_3216Metric_Pad1.33x1.80mm_HandSolder

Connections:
GND: B1.1, B2.1, B3.1, B4.1, C4.2, C7.2, C9.2, C10.2, C12.2, C17.2, C18.2, C19.2, C20.2, C21.2, C23.2, C24.2, H1.1, H2.1, H3.1, H4.1, J1.2 (Ext), J2.2 (Ext), J3.2, J4.2 (Ext), Power1.2, Q3.3 (S), Q4.3 (S), Q6.2 (E), T1.5, U7.2 (GND), U7.4 (IN-), U8.2 (GND), U8.4 (IN-)
unnamed: C17.1, L1.1, c8.1
unnamed: D8.2 (A), Q5.1 (G), Q6.3 (C), R14.2
unnamed: J1.1 (In), U8.3 (IN+)
unnamed: C18.1, J2.1 (In), L1.2
unnamed: J4.1 (In), U7.3 (IN+)
unnamed: Q3.2 (D), T1.1
unnamed: Q3.1 (G), U8.5 (OUT)
unnamed: Q4.2 (D), T1.3
unnamed: Q4.1 (G), U7.5 (OUT)
unnamed: Q6.1 (B), R15.1
unnamed: T1.4, c8.2
PTT: J3.1, R15.2
VDC: B1.2, B2.2, B3.2, B4.2, C4.1, C7.1, C9.1, C10.1, C12.1, C19.1, C20.1, C21.1, Q5.2 (D), T1.2, U7.1 (VDD), U8.1 (VDD)
VIN: C23.1, C24.1, D8.1 (K), Power1.1, Q5.3 (S), R14.1

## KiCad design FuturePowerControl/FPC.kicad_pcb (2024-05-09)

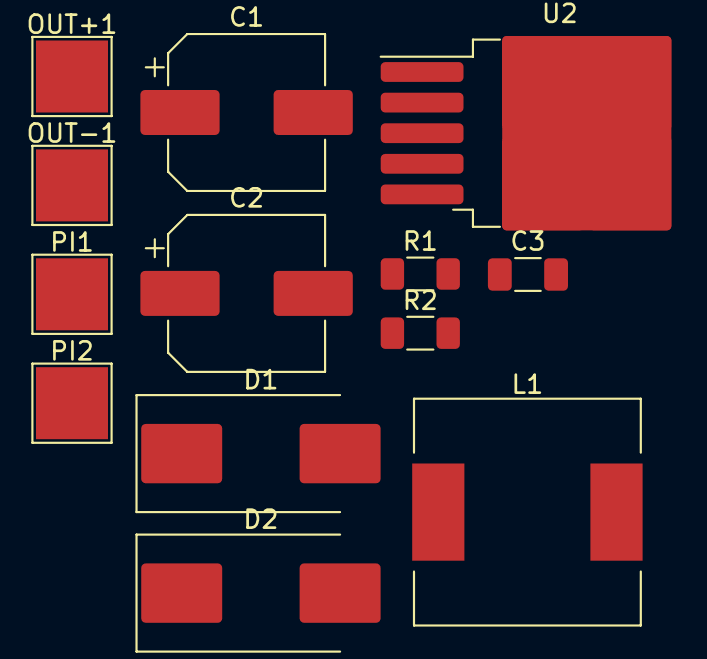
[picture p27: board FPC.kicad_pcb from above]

Board: 2 copper layers, 13 parts (0 on the bottom side), 6 nets, no tracks yet.

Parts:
C1: 220u; CP_Elec_8x10.5
C2: 470uF; CP_Elec_8x10.5
C3: 100n; C_1206_3216Metric_Pad1.33x1.80mm_HandSolder
D1, D2: SS54; D_SMC_Handsoldering
L1: 68uH; L_12x12mm_H6mm
OUT+1: OVDC; TestPoint_Pad_4.0x4.0mm
OUT-1: GND; TestPoint_Pad_4.0x4.0mm
PI1: VDC; TestPoint_Pad_4.0x4.0mm
PI2: GND; TestPoint_Pad_4.0x4.0mm
R1: 270; R_1206_3216Metric_Pad1.30x1.75mm_HandSolder
R2: 5k; R_1206_3216Metric_Pad1.30x1.75mm_HandSolder
U2: LM2596S-ADJ; TO-263-5_TabPin3

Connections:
+VDC: D2.2 (A), PI1.1
GND: C1.2, C2.2, C3.2, D1.2 (A), OUT-1.1, PI2.1, R1.2, U2.3 (GND), U2.5 (~ON/OFF)
unnamed: D1.1 (K), L1.1, U2.2 (OUT)
unnamed: C2.1, D2.1 (K), U2.1 (VIN)
unnamed: C1.1, C3.1, L1.2, OUT+1.1, R2.1
unnamed: R2.2, U2.4 (FB)

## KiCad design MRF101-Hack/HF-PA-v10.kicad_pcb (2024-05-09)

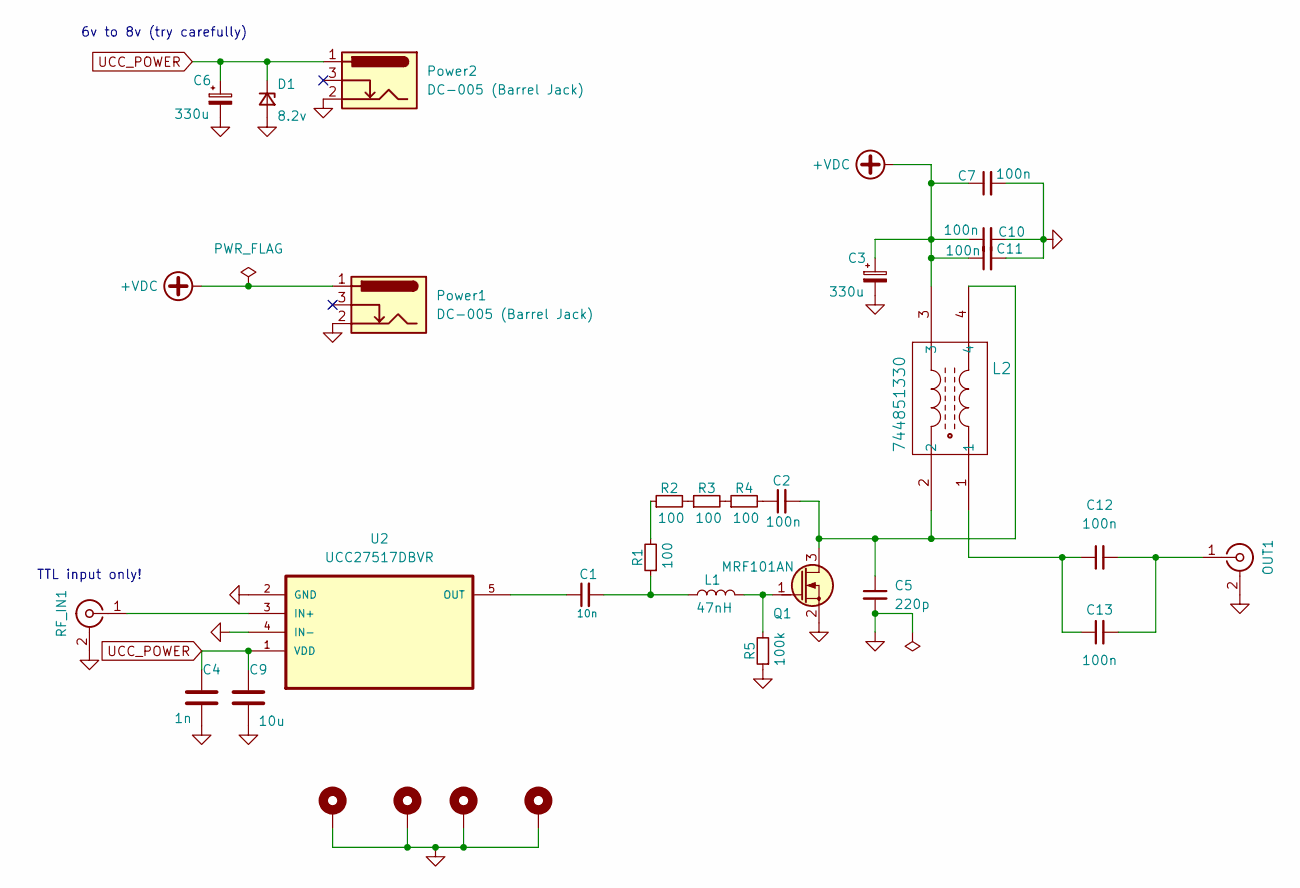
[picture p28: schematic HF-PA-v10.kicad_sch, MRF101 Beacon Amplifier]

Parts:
C1: 10n; C_1206_3216Metric_Pad1.33x1.80mm_HandSolder
C2, C7, C10, C11, C12, C13: 100n; C_1206_3216Metric_Pad1.33x1.80mm_HandSolder
C3, C6: 330u; C_Radial_D10.0mm_H12.5mm_P5.00mm
C4: 1n; C_1206_3216Metric_Pad1.33x1.80mm_HandSolder
C5: 220p; C_1206_3216Metric_Pad1.33x1.80mm_HandSolder
C9: 10u; C_1206_3216Metric_Pad1.33x1.80mm_HandSolder
D1: 8.2v; D_DO-35_SOD27_P3.81mm_Vertical_KathodeUp
H1, H2, H3, H4: MountingHole_Pad; MountingHole_3.2mm_M3_Pad_Via
L1: 47nH; WE-CAIR_4248
L2: 744851330; 744851330_WRE
OUT1: SMA; SMA_Samtec_SMA-J-P-X-ST-EM1_EdgeMount
Power1, Power2: DC-005 (Barrel Jack); XKB_DC-005-5A-2.0_Modded
Q1: MRF101AN; TO-220-3_Horizontal_TabDown
R1, R2, R3, R4: 100; R_2512_6332Metric_Pad1.40x3.35mm_HandSolder
R5: 100k; R_2512_6332Metric_Pad1.40x3.35mm_HandSolder
RF_IN1: SMA; SMA_Samtec_SMA-J-P-X-ST-EM1_EdgeMount
U2: UCC27517DBVR; SOT-23-5_HandSoldering

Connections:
+VDC: C3.1, C7.1, C10.1, C11.1, L2.3, Power1.1
GND: C3.2, C4.2, C5.2, C6.2, C7.2, C9.2, C10.2, C11.2, D1.2 (A), H1.1, H2.1, H3.1, H4.1, OUT1.2 (Ext), Power1.2, Power2.2, Q1.2 (S), R5.1, RF_IN1.2 (Ext), U2.2 (GND), U2.4 (IN-)
unnamed: C1.2, L1.1, R1.1
unnamed: C2.1, R4.2
unnamed: C12.1, C13.1, L2.1
unnamed: C12.2, C13.2, OUT1.1 (In)
unnamed: C2.2, C5.1, L2.2, L2.4, Q1.3 (D)
unnamed: L1.2, Q1.1 (G), R5.2
unnamed: R1.2, R2.1
unnamed: R2.2, R3.1
unnamed: R3.2, R4.1
unnamed: RF_IN1.1 (In), U2.3 (IN+)
unnamed: C1.1, U2.5 (OUT)
UCC_POWER: C4.1, C6.1, C9.1, D1.1 (K), Power2.1, U2.1 (VDD)

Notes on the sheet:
TTL input only!
6v to 8v (try carefully)

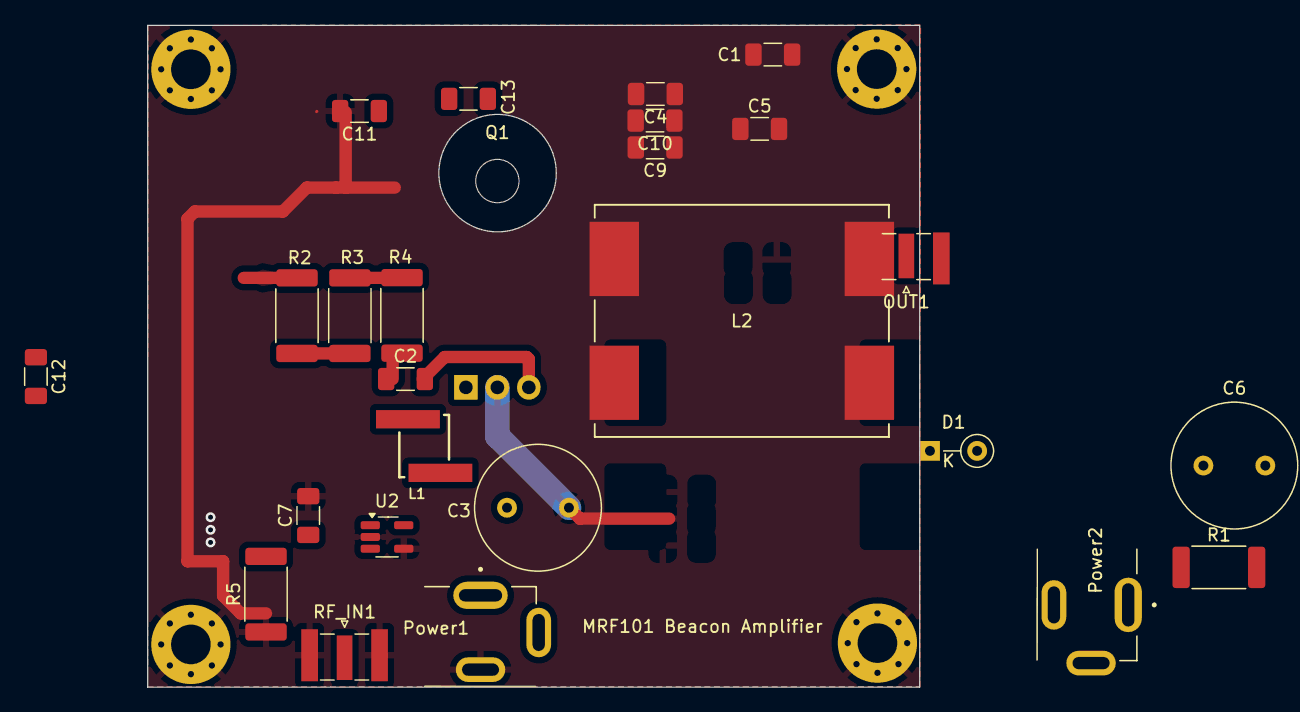
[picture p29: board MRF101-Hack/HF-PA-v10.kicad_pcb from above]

Board: 2 copper layers, 62.3 x 53.4 mm, 30 parts (0 on the bottom side), 14 nets.

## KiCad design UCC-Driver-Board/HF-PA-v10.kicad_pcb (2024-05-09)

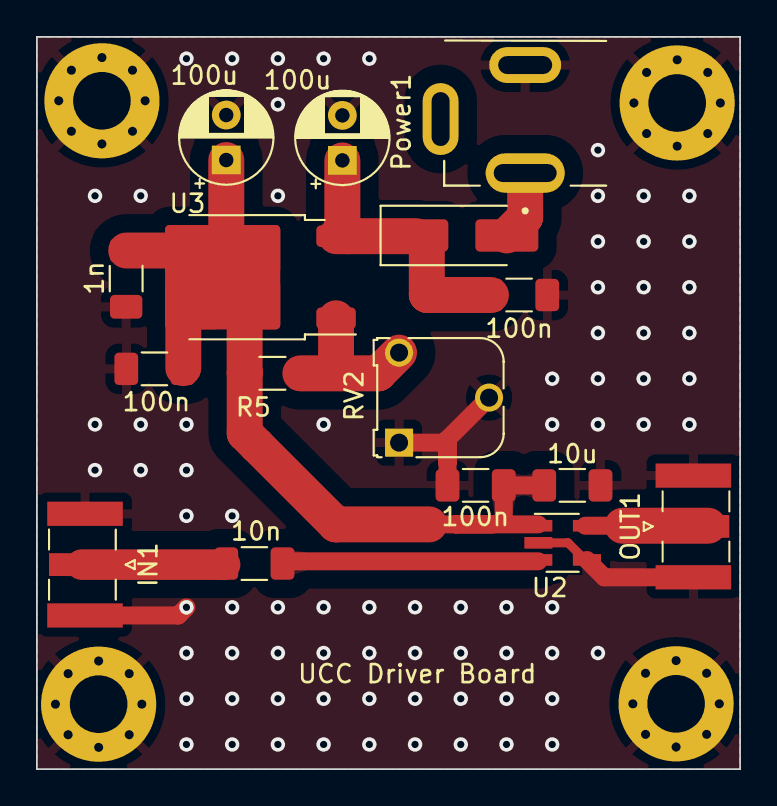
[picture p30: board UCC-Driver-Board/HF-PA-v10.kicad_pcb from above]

Board: 2 copper layers, 39.1 x 40.7 mm, 20 parts (0 on the bottom side), 8 nets.

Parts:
C5, C15: 100u; CP_Radial_D5.0mm_P2.50mm
C6, C14, C23: 100n; C_1206_3216Metric_Pad1.33x1.80mm_HandSolder
C16: 10u; C_1206_3216Metric_Pad1.33x1.80mm_HandSolder
C17: 1n; C_1206_3216Metric_Pad1.33x1.80mm_HandSolder
C19: 10n; C_1206_3216Metric_Pad1.33x1.80mm_HandSolder
D1: SS34; D_SMA_Handsoldering
H1, H2, H3, H4: MountingHole_Pad; MountingHole_3.2mm_M3_Pad_Via
IN1: SMA; SMA_Samtec_SMA-J-P-X-ST-EM1_EdgeMount
OUT1: SMA; SMA_Samtec_SMA-J-P-X-ST-EM1_EdgeMount
Power1: DC-005 (Barrel Jack); XKB_DC-005-5A-2.0_Modded
R5: 220; R_1206_3216Metric_Pad1.30x1.75mm_HandSolder
RV2: 5k; Potentiometer_Runtron_RM-065_Vertical
U2: UCC27517DBVR; SOT-23-5_HandSoldering
U3: LM317_TO-252; TO-252-2

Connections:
12V: C5.1, C6.1, C16.1, C17.1, C23.1, R5.1, U2.1 (VDD), U3.2 (VO)
+VDC: D1.2 (A), Power1.1
GND: C5.2, C6.2, C14.2, C15.2, C16.2, C17.2, C23.2, H1.1, H2.1, H3.1, H4.1, IN1.2 (Ext), OUT1.2 (Ext), Power1.2, RV2.1, RV2.2, U2.2 (GND), U2.4 (IN-)
unnamed: C14.1, C15.1, D1.1 (K), U3.3 (VI)
unnamed: C19.1, IN1.1 (In)
unnamed: OUT1.1 (In), U2.5 (OUT)
unnamed: C19.2, U2.3 (IN+)
unnamed: R5.2, RV2.3, U3.1 (ADJ)

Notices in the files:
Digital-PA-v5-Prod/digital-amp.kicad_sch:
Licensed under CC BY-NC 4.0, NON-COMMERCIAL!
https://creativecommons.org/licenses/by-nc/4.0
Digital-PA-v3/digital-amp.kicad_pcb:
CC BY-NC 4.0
